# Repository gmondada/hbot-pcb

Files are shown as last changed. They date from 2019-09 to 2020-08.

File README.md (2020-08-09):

# HBOT - PCB

This is the KiCad projet for a 24-RC-servo controller. It has been designed to control the [HBOT Humanoid Robot](https://github.com/gmondada/hbot-main). It is based on a STM32F4 (Cortex M4) microcontroller and has a socket to hold a WEMOS D1 mini.

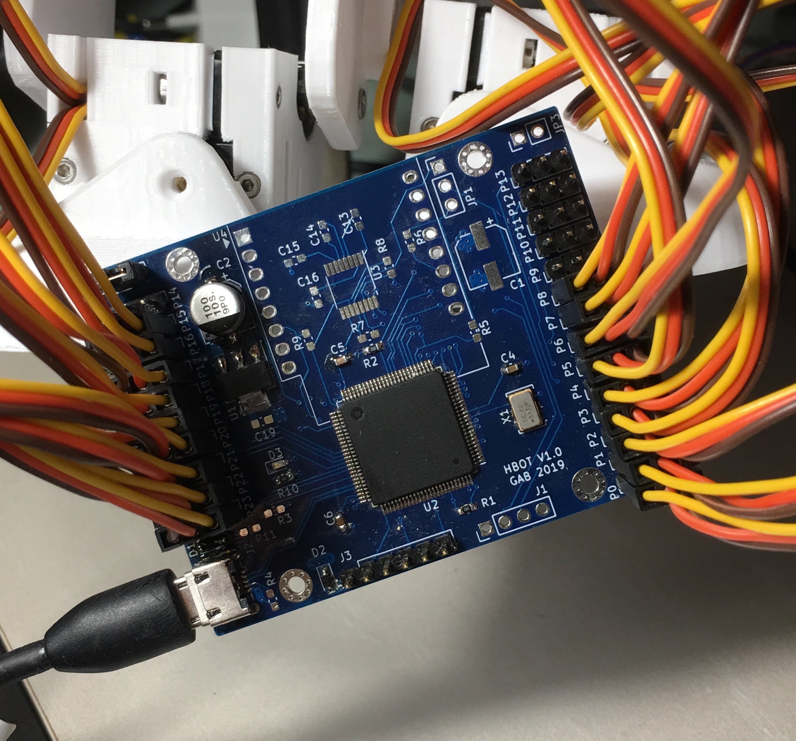
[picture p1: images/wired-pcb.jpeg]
pcb


# The HBOT in action

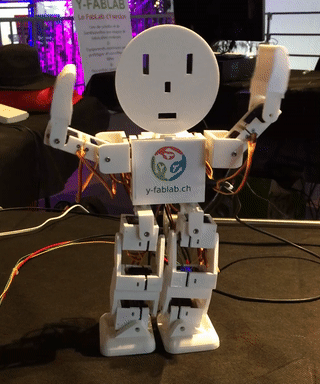
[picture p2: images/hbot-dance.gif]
dance


See [Full Demo on YouTube](https://youtu.be/EHFqUxe0FO4).

# License

Copyright (c) 2019 Gabriele Mondada.
Licensed under the [Creative Commons CC-BY 4.0 License](https://creativecommons.org/licenses/by/4.0/legalcode).

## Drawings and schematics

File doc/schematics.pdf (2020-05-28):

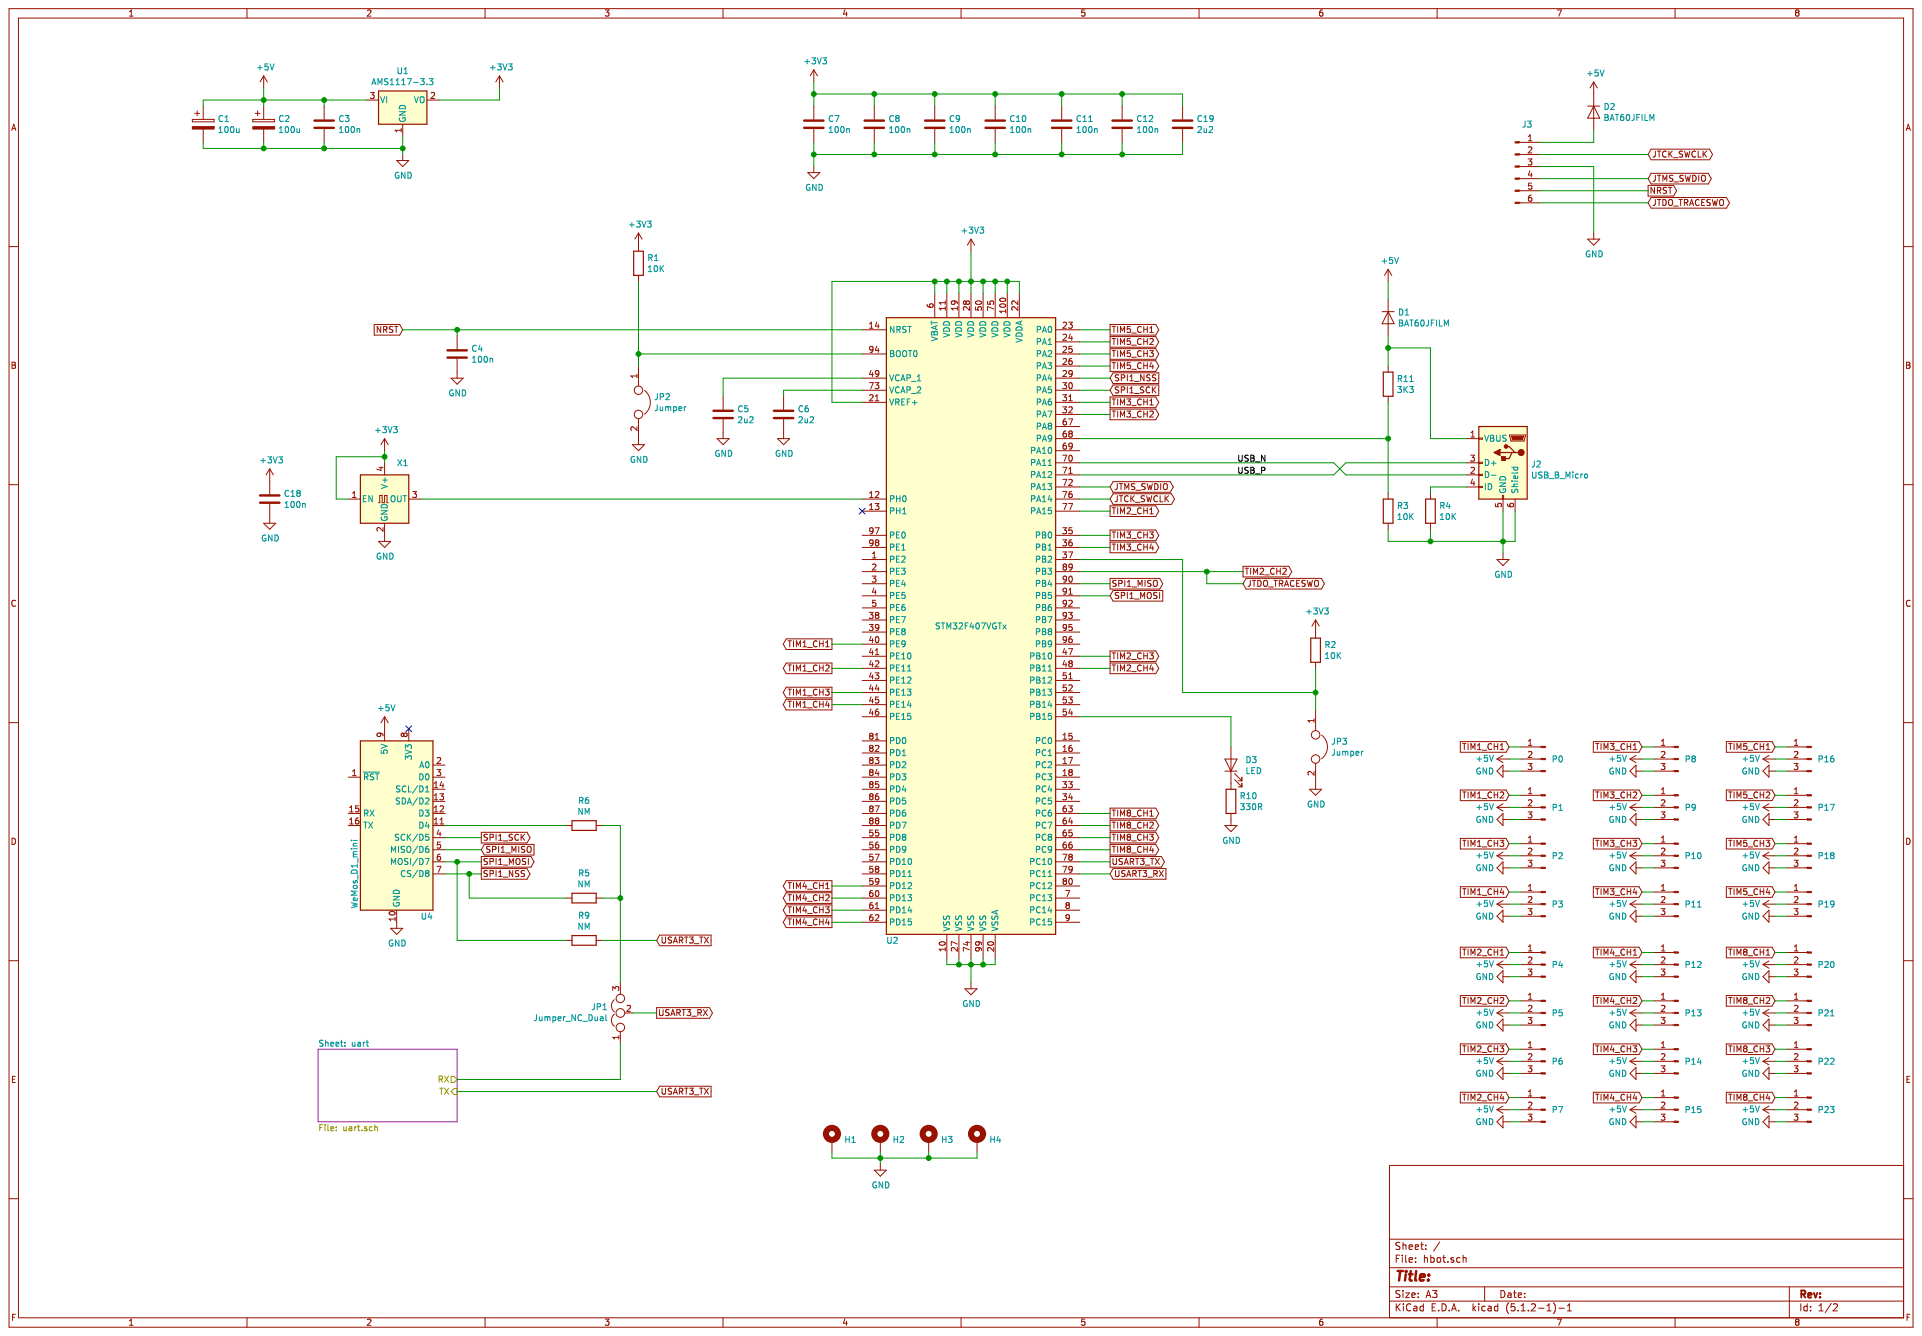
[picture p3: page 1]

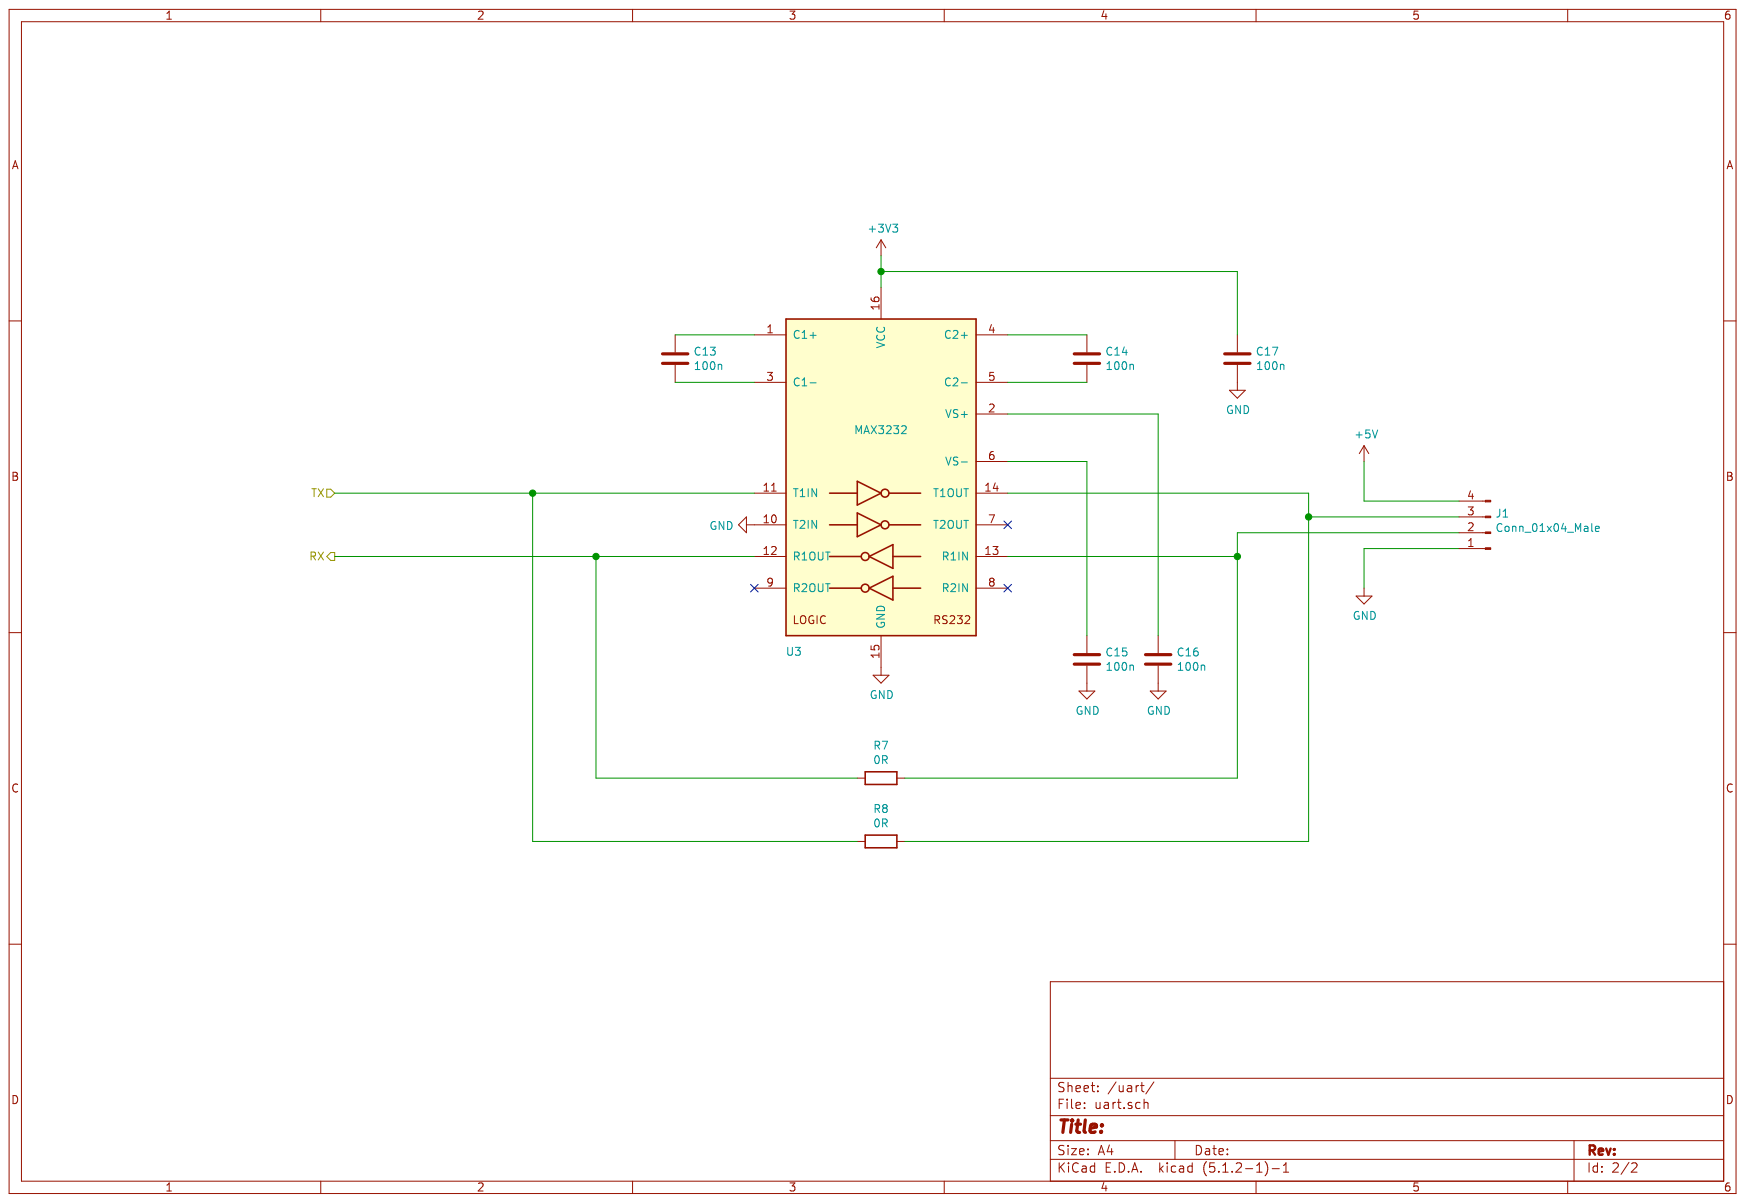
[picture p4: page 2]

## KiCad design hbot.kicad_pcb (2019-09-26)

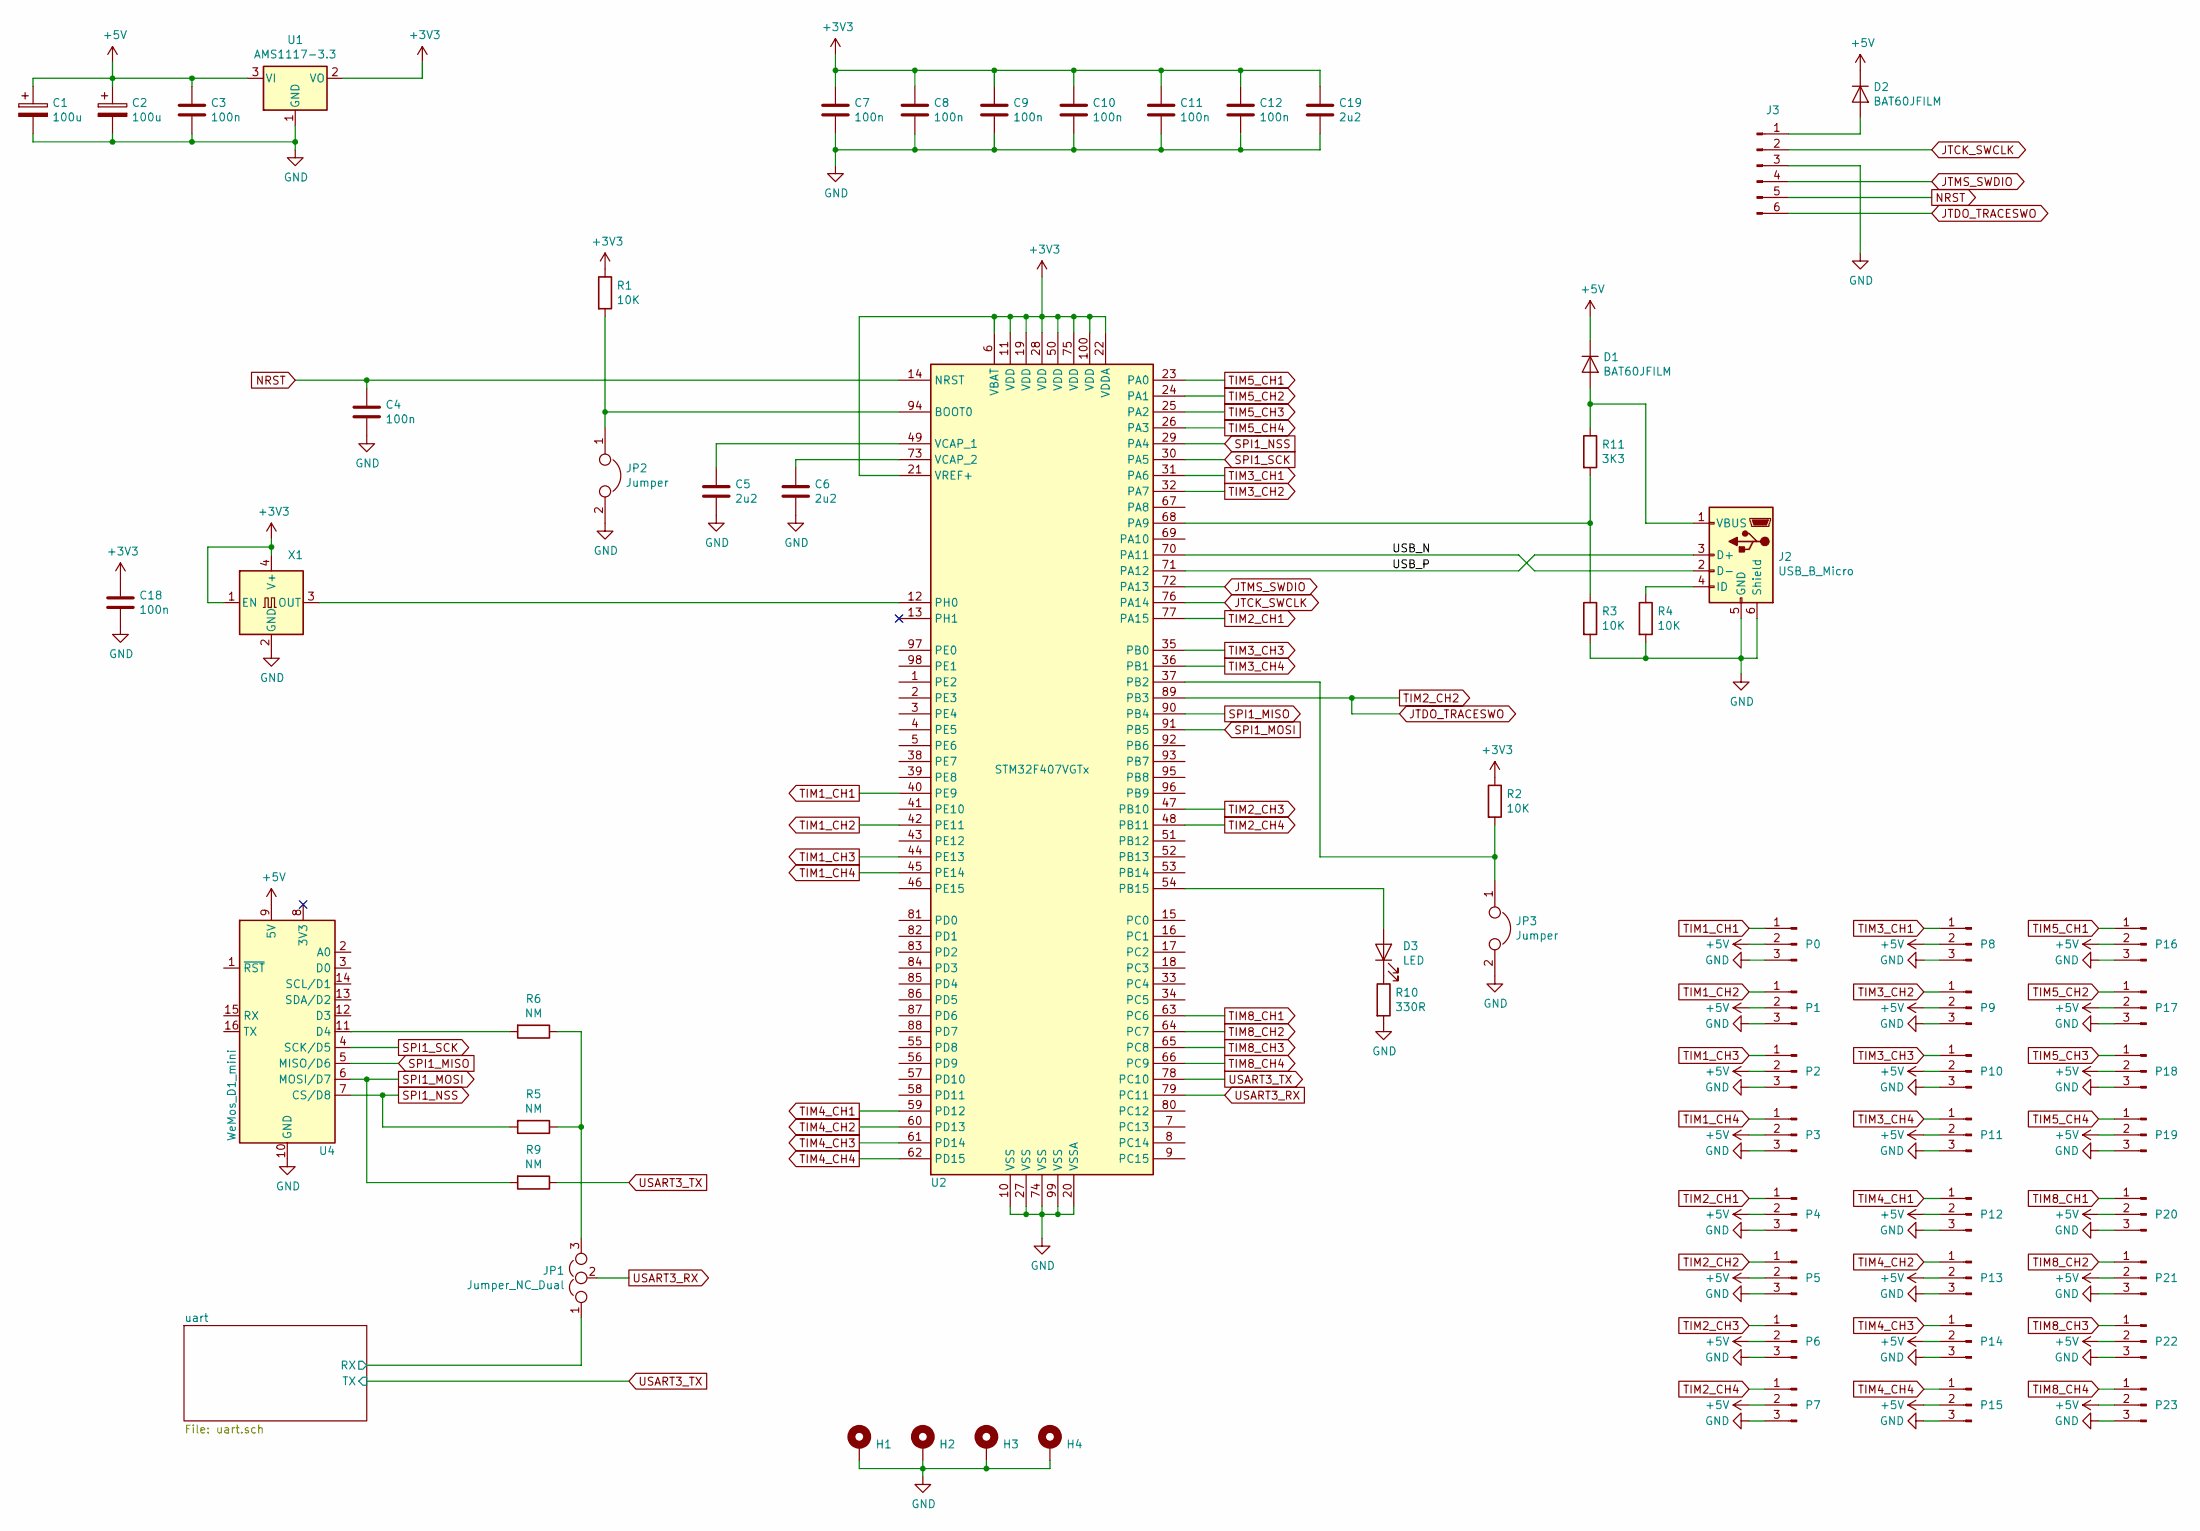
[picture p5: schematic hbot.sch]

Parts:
C1, C2: 100u; CP_Elec_6.3x7.7
C3, C4, C7, C8, C9, C10, C11, C12, C18: 100n; C_0603_1608Metric_Pad1.05x0.95mm_HandSolder
C5, C6, C19: 2u2; C_0603_1608Metric_Pad1.05x0.95mm_HandSolder
D1, D2: BAT60JFILM; D_SOD-323_HandSoldering
D3: LED; LED_0603_1608Metric_Pad1.05x0.95mm_HandSolder
H1, H2, H3, H4: MountingHole_Pad; MountingHole_2.2mm_M2_Pad_Via
J2: USB_B_Micro; USB_Micro-B_Wuerth_629105150521
J3: Conn_01x06_Male; PinHeader_1x06_P2.54mm_Vertical
JP1: Jumper_NC_Dual; PinHeader_1x03_P2.54mm_Vertical
JP2, JP3: Jumper; PinHeader_1x02_P2.54mm_Vertical
P0, P1, P2, P3, P4, P5, P6, P7, P8, P9, P10, P11, P12, P13, P14, P15, P16, P17, P18, P19, P20, P21, P22, P23: Conn_01x03_Male; PinHeader_1x03_P2.54mm_Vertical
R1, R2, R3, R4: 10K; R_0603_1608Metric_Pad1.05x0.95mm_HandSolder
R5, R6, R9: NM; R_0603_1608Metric_Pad1.05x0.95mm_HandSolder
R10: 330R; R_0603_1608Metric_Pad1.05x0.95mm_HandSolder
R11: 3K3; R_0603_1608Metric_Pad1.05x0.95mm_HandSolder
U1: AMS1117-3.3; SOT-223-3_TabPin2
U2: STM32F407VGTx; LQFP-100_14x14mm_P0.5mm
U4: WeMos_D1_mini; WEMOS_D1_mini_light
X1: XO53; Oscillator_SMD_EuroQuartz_XO53-4Pin_5.0x3.2mm

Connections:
+3V3: C7.1, C8.1, C9.1, C10.1, C11.1, C12.1, C18.1, C19.1, R1.1, R2.1, U1.2 (VO), U2.6 (VBAT), U2.11 (VDD), U2.19 (VDD), U2.21 (VREF+), U2.22 (VDDA), U2.28 (VDD), U2.50 (VDD), U2.75 (VDD), U2.100 (VDD), X1.1 (EN), X1.4 (V+); also elsewhere on the board
+5V: C1.1, C2.1, C3.1, D1.1 (K), D2.1 (K), P0.2, P1.2, P2.2, P3.2, P4.2, P5.2, P6.2, P7.2, P8.2, P9.2, P10.2, P11.2, P12.2, P13.2, P14.2, P15.2, P16.2, P17.2, P18.2, P19.2, P20.2, P21.2, P22.2, P23.2, U1.3 (VI), U4.9 (5V); also elsewhere on the board
/USB_N: J2.2 (D-), U2.70 (PA11)
/USB_P: J2.3 (D+), U2.71 (PA12)
/uart/RX: JP1.1; also elsewhere on the board
GND: C1.2, C2.2, C3.2, C4.2, C5.2, C6.2, C7.2, C8.2, C9.2, C10.2, C11.2, C12.2, C18.2, C19.2, H1.1, H2.1, H3.1, H4.1, J2.5 (GND), J2.6 (Shield), J3.3, JP2.2, JP3.2, P0.3, P1.3, P2.3, P3.3, P4.3, P5.3, P6.3, P7.3, P8.3, P9.3, P10.3, P11.3, P12.3, P13.3, P14.3, P15.3, P16.3, P17.3, P18.3, P19.3, P20.3, P21.3, P22.3, P23.3, R3.2, R4.2, R10.2, U1.1 (GND), U2.10 (VSS), U2.20 (VSSA), U2.27 (VSS), U2.74 (VSS), U2.99 (VSS), U4.10 (GND), X1.2 (GND); also elsewhere on the board
JTCK_SWCLK: J3.2, U2.76 (PA14)
JTDO_TRACESWO: J3.6, P5.1, U2.89 (PB3)
JTMS_SWDIO: J3.4, U2.72 (PA13)
NRST: C4.1, J3.5, U2.14 (NRST)
unnamed: C5.1, U2.49 (VCAP_1)
unnamed: C6.1, U2.73 (VCAP_2)
unnamed: D1.2 (A), J2.1 (VBUS), R11.1
unnamed: D2.2 (A), J3.1
unnamed: D3.1 (K), R10.1
unnamed: D3.2 (A), U2.54 (PB15)
unnamed: J2.4 (ID), R4.1
unnamed: JP1.3, R5.1, R6.1
unnamed: JP2.1, R1.2, U2.94 (BOOT0)
unnamed: JP3.1, R2.2, U2.37 (PB2)
unnamed: R6.2, U4.11 (D4)
unnamed: R3.1, R11.2, U2.68 (PA9)
unnamed: U2.12 (PH0), X1.3 (OUT)
SPI1_MISO: U2.90 (PB4), U4.5 (MISO/D6)
SPI1_MOSI: R9.2, U2.91 (PB5), U4.6 (MOSI/D7)
SPI1_NSS: R5.2, U2.29 (PA4), U4.7 (CS/D8)
SPI1_SCK: U2.30 (PA5), U4.4 (SCK/D5)
TIM1_CH1: P0.1, U2.40 (PE9)
TIM1_CH2: P1.1, U2.42 (PE11)
TIM1_CH3: P2.1, U2.44 (PE13)
TIM1_CH4: P3.1, U2.45 (PE14)
TIM2_CH1: P4.1, U2.77 (PA15)
TIM2_CH3: P6.1, U2.47 (PB10)
TIM2_CH4: P7.1, U2.48 (PB11)
TIM3_CH1: P8.1, U2.31 (PA6)
TIM3_CH2: P9.1, U2.32 (PA7)
TIM3_CH3: P10.1, U2.35 (PB0)
TIM3_CH4: P11.1, U2.36 (PB1)
TIM4_CH1: P12.1, U2.59 (PD12)
TIM4_CH2: P13.1, U2.60 (PD13)
TIM4_CH3: P14.1, U2.61 (PD14)
TIM4_CH4: P15.1, U2.62 (PD15)
TIM5_CH1: P16.1, U2.23 (PA0)
TIM5_CH2: P17.1, U2.24 (PA1)
TIM5_CH3: P18.1, U2.25 (PA2)
TIM5_CH4: P19.1, U2.26 (PA3)
TIM8_CH1: P20.1, U2.63 (PC6)
TIM8_CH2: P21.1, U2.64 (PC7)
TIM8_CH3: P22.1, U2.65 (PC8)
TIM8_CH4: P23.1, U2.66 (PC9)
USART3_RX: JP1.2, U2.79 (PC11)
USART3_TX: R9.1, U2.78 (PC10); also elsewhere on the board

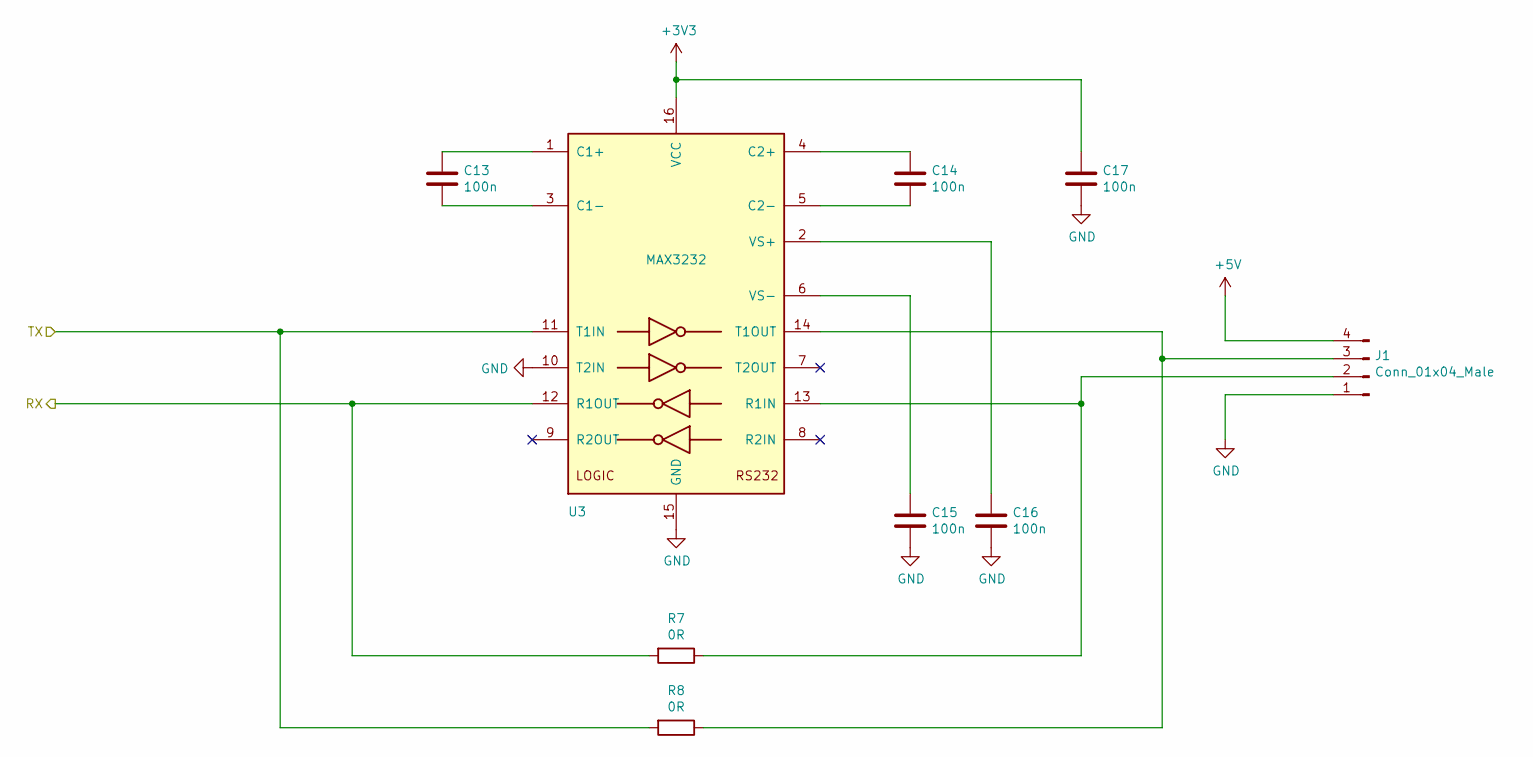
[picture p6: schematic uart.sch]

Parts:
C13, C14, C15, C16, C17: 100n; C_0603_1608Metric_Pad1.05x0.95mm_HandSolder
J1: Conn_01x04_Male; PinHeader_1x04_P2.54mm_Vertical
R7, R8: 0R; R_0603_1608Metric_Pad1.05x0.95mm_HandSolder
U3: MAX3232; TSSOP-16_4.4x5mm_P0.65mm

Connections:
+3V3: C17.1, U3.16 (VCC); also elsewhere on the board
+5V: J1.4; also elsewhere on the board
/uart/RX: R7.2, U3.12 (R1OUT); also elsewhere on the board
GND: C15.2, C16.2, C17.2, J1.1, U3.10 (T2IN), U3.15 (GND); also elsewhere on the board
unnamed: C13.1, U3.1 (C1+)
unnamed: C13.2, U3.3 (C1-)
unnamed: C14.1, U3.4 (C2+)
unnamed: C14.2, U3.5 (C2-)
unnamed: C15.1, U3.6 (VS-)
unnamed: C16.1, U3.2 (VS+)
unnamed: J1.2, R7.1, U3.13 (R1IN)
unnamed: J1.3, R8.1, U3.14 (T1OUT)
USART3_TX: R8.2, U3.11 (T1IN); also elsewhere on the board

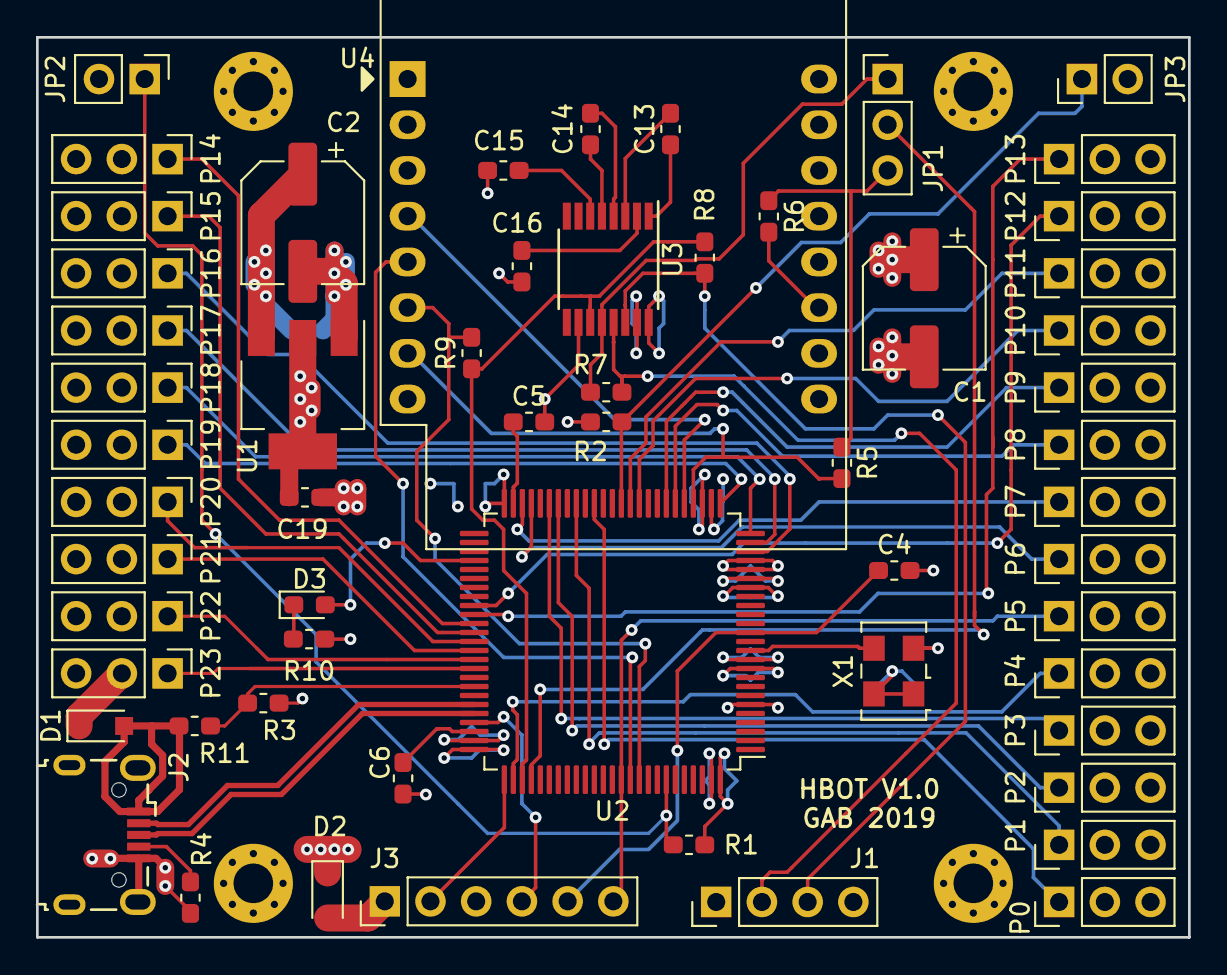
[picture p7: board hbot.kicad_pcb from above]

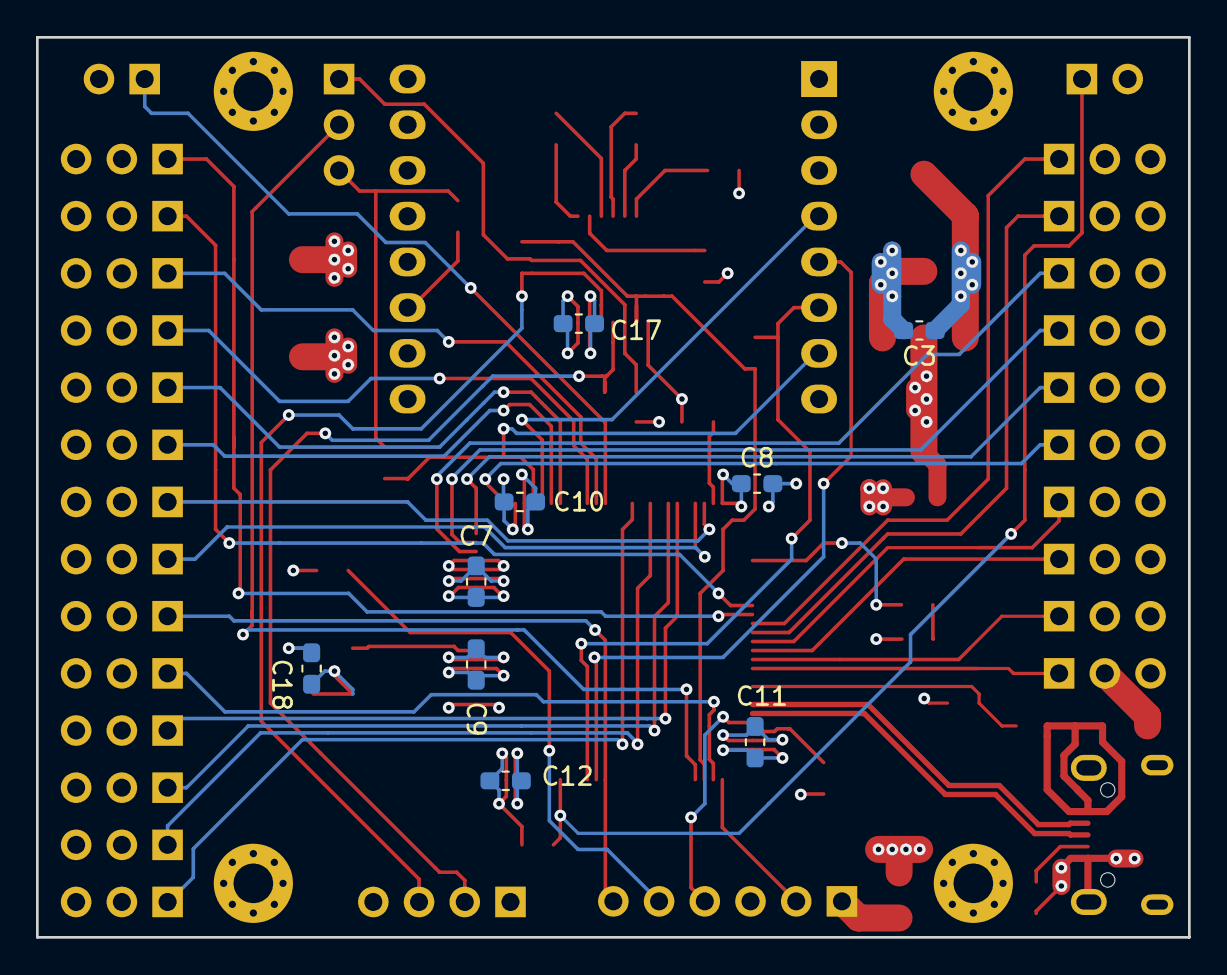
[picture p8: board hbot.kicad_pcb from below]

Board: 4 copper layers, 64.0 x 50.0 mm, 72 parts (9 on the bottom side), 60 nets.

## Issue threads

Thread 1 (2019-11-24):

misuse of pin 1 on JTAG connector

gmondada, 2019-11-24:
J3 (JTAG/SWD connector) pin 1 should be used to monitor the voltage of the STM, not to supply power to the board.
Workaround: D2 should be kept unmounted and J3.1 should be wired to C11.

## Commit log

2019-09-26 version 1.0
    [hbot.kicad_pcb, hbot.sch, uart.sch]
2019-09-26 add manufacturing files
    [hbot-B_Cu.gbr, hbot-B_Mask.gbr, hbot-B_SilkS.gbr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]
2020-05-28 add schematics in PDF format
